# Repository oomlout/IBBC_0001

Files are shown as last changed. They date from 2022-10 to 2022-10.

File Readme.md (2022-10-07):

# IBBC - 0001 - ADXL345 Breakout  

## Chips

### ADXL345 -- SENS-LG14-X-K345-01

https://www.analog.com/en/products/adxl345.html
https://github.com/oomlout/oomlout_OOMP_parts/tree/main/SENS-LG14-X-K345-01

## Other Breakouts  

	Adafruit
	https://www.adafruit.com/product/1231
	https://github.com/adafruit/Adafruit_ADXL345_PCB
	https://github.com/oomlout/oomlout_OOMP_projects/tree/main/PROJ-ADAF-1231-STAN-01
	
	Sparkfun
	https://www.sparkfun.com/products/9836
	https://github.com/sparkfun/ADXL345_Breakout
	https://github.com/oomlout/oomlout_OOMP_projects/tree/main/PROJ-SPAR-9836-STAN-01
	
	Analog
	https://www.analog.com/en/products/adxl345.html#product-evaluationkit
	https://github.com/oomlout/oomlout_OOMP_projects/tree/main/PROJ-ANLG-0345-STAN-01
	
	Seed
	https://github.com/oomlout/oomlout_OOMP_projects/tree/main/PROJ-SEED-20054-STAN-01

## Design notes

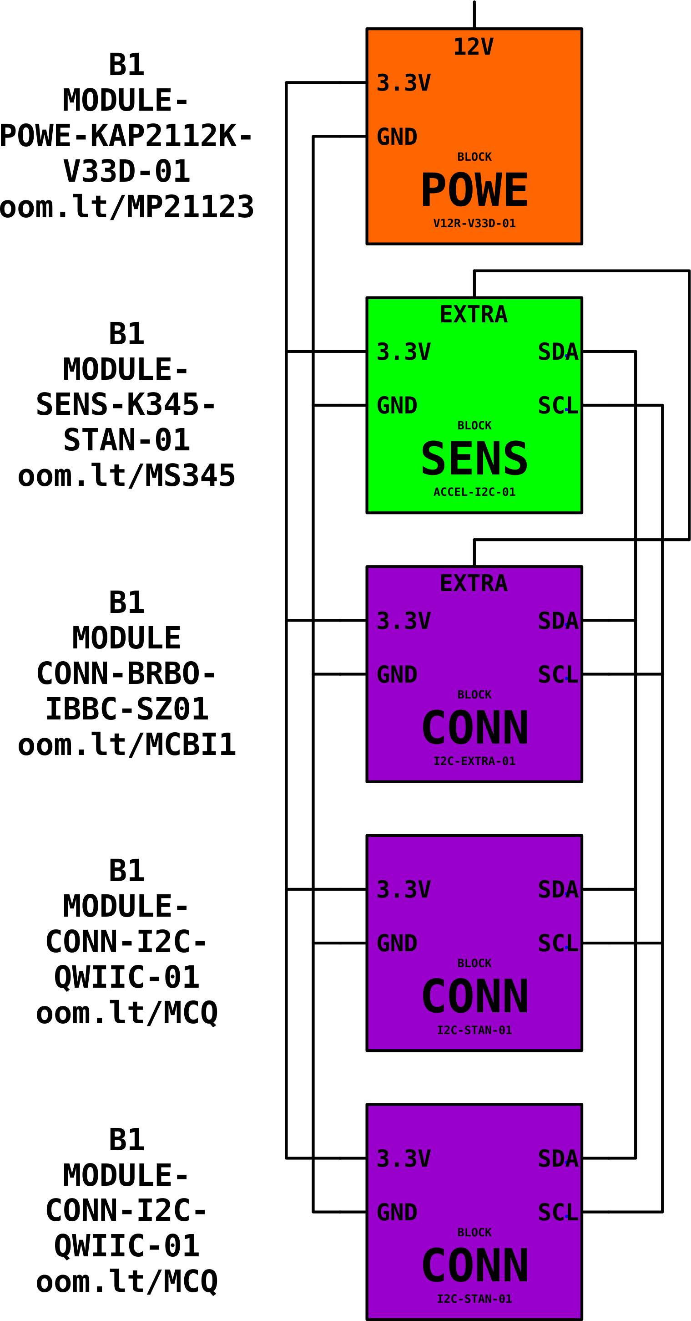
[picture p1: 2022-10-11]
working/block.png

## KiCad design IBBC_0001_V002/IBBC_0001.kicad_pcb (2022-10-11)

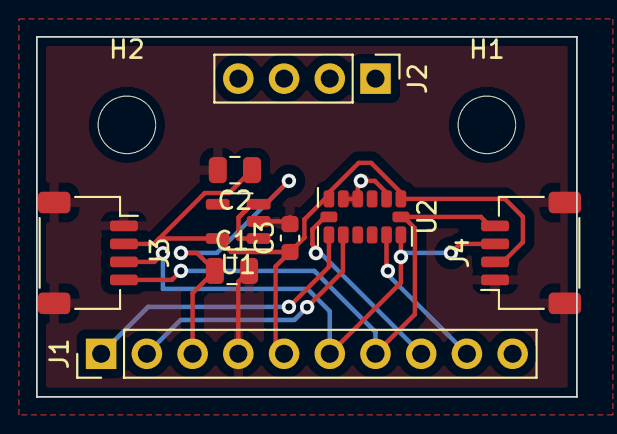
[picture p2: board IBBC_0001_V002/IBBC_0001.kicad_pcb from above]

Board: 2 copper layers, 30.0 x 20.0 mm, 11 parts (0 on the bottom side), 9 nets.

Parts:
C1, C2: 10uf; C_0805_2012Metric
C3: 100nf; C_0603_1608Metric
H1, H2: MountingHole; MountingHole_3.2mm_M3
J1: HEAD-I01-X-PI10-01 oom.lt/H10; PinHeader_1x10_P2.54mm_Vertical
J2: HEAD-I01-X-PI04-01 oom.lt/H4; PinHeader_1x04_P2.54mm_Vertical
J3, J4: HEAD-JSTSH-X-PI04-RS oom.lt/HSHR4; JST_SH_SM04B-SRSS-TB_1x04-1MP_P1.00mm_Horizontal
U1: AP2112K-3.3; SOT-23-5
U2: ADXL343; LGA-14_3x5mm_P0.8mm_LayoutBorder1x6y

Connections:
3v3: C2.1, C3.1, J1.5, J3.2, J4.2, U1.5 (VOUT), U2.1 (Vdd_I/O), U2.6 (Vs)
CS: J1.8, U2.7 (~CS)
EX01: J1.1, U2.8 (INT1)
EX02: J1.2, U2.9 (INT2)
EX03: J1.9, U2.12 (SDO/ADDR)
GND: C1.2, C2.2, C3.2, J1.4, J3.1, J3.MP (MountPin), J4.1, J4.MP (MountPin), U1.2 (GND), U2.2 (GND), U2.4 (GND), U2.5 (GND)
SCL: J1.7, J3.4, J4.4, U2.14 (SCL/SCLK)
SDA: J1.6, J3.3, J4.3, U2.13 (SDA/SDI/SDIO)
Vin: C1.1, J1.3, U1.1 (VIN), U1.3 (EN)

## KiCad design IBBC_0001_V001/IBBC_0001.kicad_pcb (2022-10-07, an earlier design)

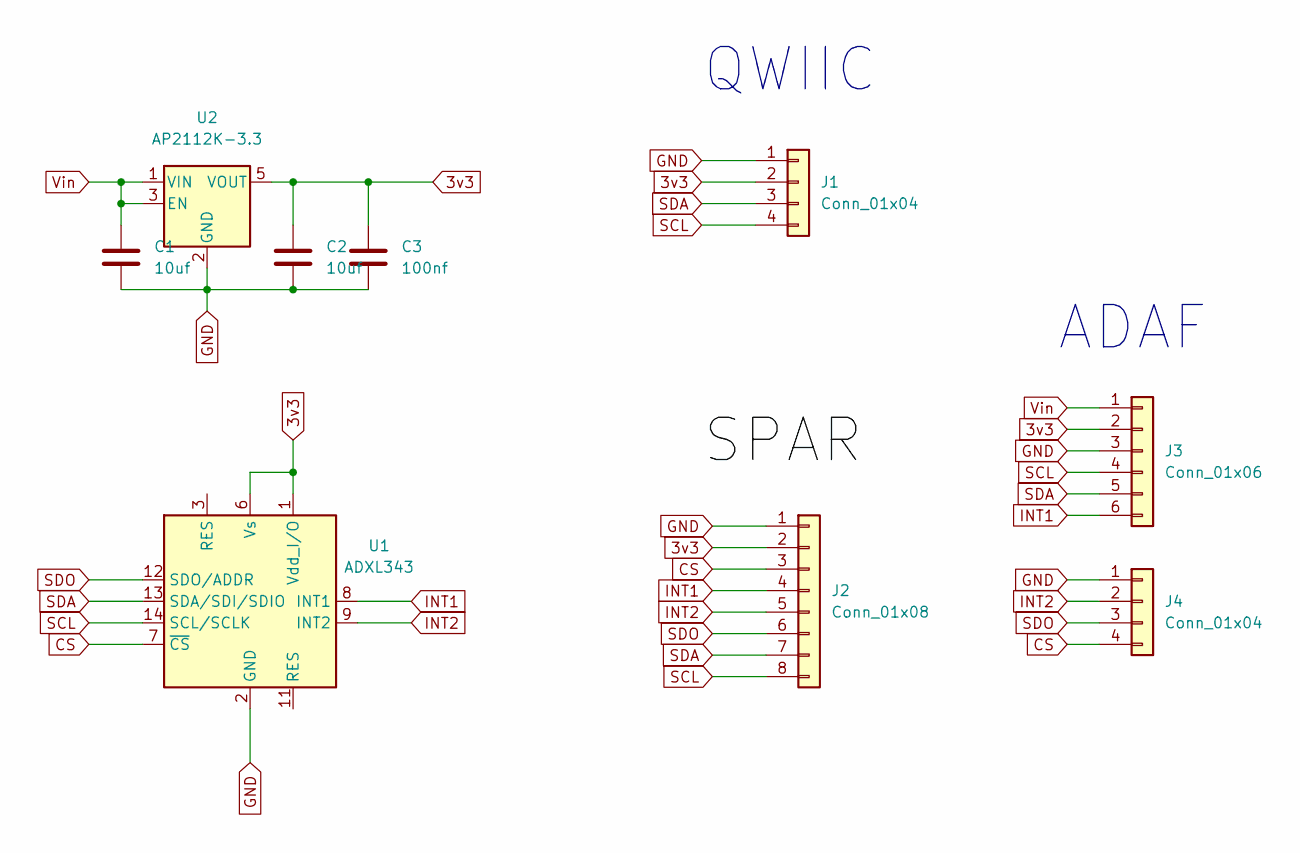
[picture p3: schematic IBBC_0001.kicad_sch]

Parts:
C1, C2: 10uf; C_0805_2012Metric_Pad1.18x1.45mm_HandSolder
C3: 100nf; C_0603_1608Metric_Pad1.08x0.95mm_HandSolder
J1: Conn_01x04; JST_SH_SM04B-SRSS-TB_1x04-1MP_P1.00mm_Horizontal
J2: Conn_01x08; PinHeader_1x08_P2.54mm_Vertical
J3: Conn_01x06; PinHeader_1x06_P2.54mm_Vertical
J4: Conn_01x04; PinHeader_1x04_P2.54mm_Vertical
U1: ADXL343; LGA-14_3x5mm_P0.8mm_LayoutBorder1x6y
U2: AP2112K-3.3; SOT-23-5_HandSoldering

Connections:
3v3: C2.1, C3.1, J1.2, J2.2, J3.2, U1.1 (Vdd_I/O), U1.6 (Vs), U2.5 (VOUT)
CS: J2.3, J4.4, U1.7 (~CS)
GND: C1.2, C2.2, C3.2, J1.1, J2.1, J3.3, J4.1, U1.2 (GND), U1.4 (GND), U1.5 (GND), U2.2 (GND)
INT1: J2.4, J3.6, U1.8 (INT1)
INT2: J2.5, J4.2, U1.9 (INT2)
SCL: J1.4, J2.8, J3.4, U1.14 (SCL/SCLK)
SDA: J1.3, J2.7, J3.5, U1.13 (SDA/SDI/SDIO)
SDO: J2.6, J4.3, U1.12 (SDO/ADDR)
Vin: C1.1, J3.1, U2.1 (VIN), U2.3 (EN)

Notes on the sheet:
QWIIC
ADAF

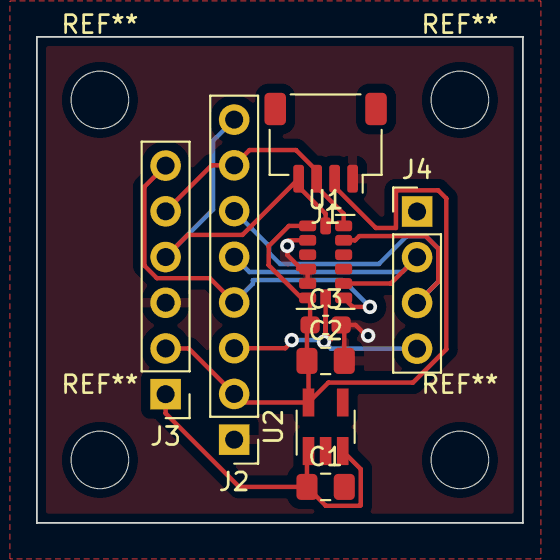
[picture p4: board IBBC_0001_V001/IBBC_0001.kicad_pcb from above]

Board: 2 copper layers, 27.0 x 27.0 mm, 9 parts (0 on the bottom side), 9 nets.

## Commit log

2022-10-07 Initial workings.
    [IBBC_0001-B_Cu.gbr, IBBC_0001-B_Mask.gbr, IBBC_0001-B_Paste.gbr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]
2022-10-11 V002 speed run.
    [IBBC_0001-B_Cu.gbr, IBBC_0001-B_Mask.gbr, IBBC_0001-B_Paste.gbr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]
2022-10-11 Fixed name of version folders.
    [IBBC_0001-B_Cu.gbr, IBBC_0001-B_Mask.gbr, IBBC_0001-B_Paste.gbr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]
2022-10-11 Moved version folders.
    [IBBC_0001-B_Cu.gbr, IBBC_0001-B_Mask.gbr, IBBC_0001-B_Paste.gbr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]
